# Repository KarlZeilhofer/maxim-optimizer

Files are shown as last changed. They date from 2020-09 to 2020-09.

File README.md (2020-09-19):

# Maxim Optimizer

This KiCad project implements a solar cell optimizer based on the Maxim MAX20801 step down controller with integreated MPPT. 

It's inputs are connected to 3 arrays of 20 to 24 solar cells, they have to be isolated on the input side of the optimizer. 

The outputs of the 3 step down controllers are connected in series. 

This kind of optimizer maximizes the output power for each cell array individually, and works perfectly if some solar modules are shaded partially in a string of many modules. 

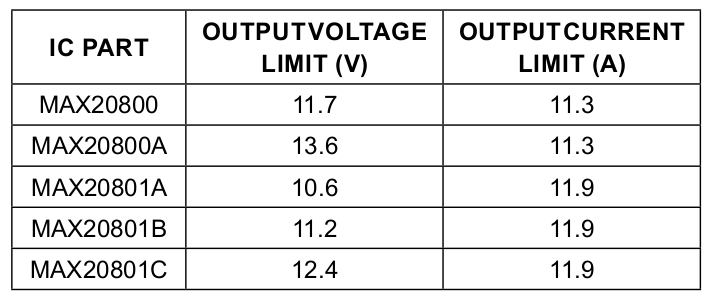
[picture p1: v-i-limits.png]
voltage and current limits


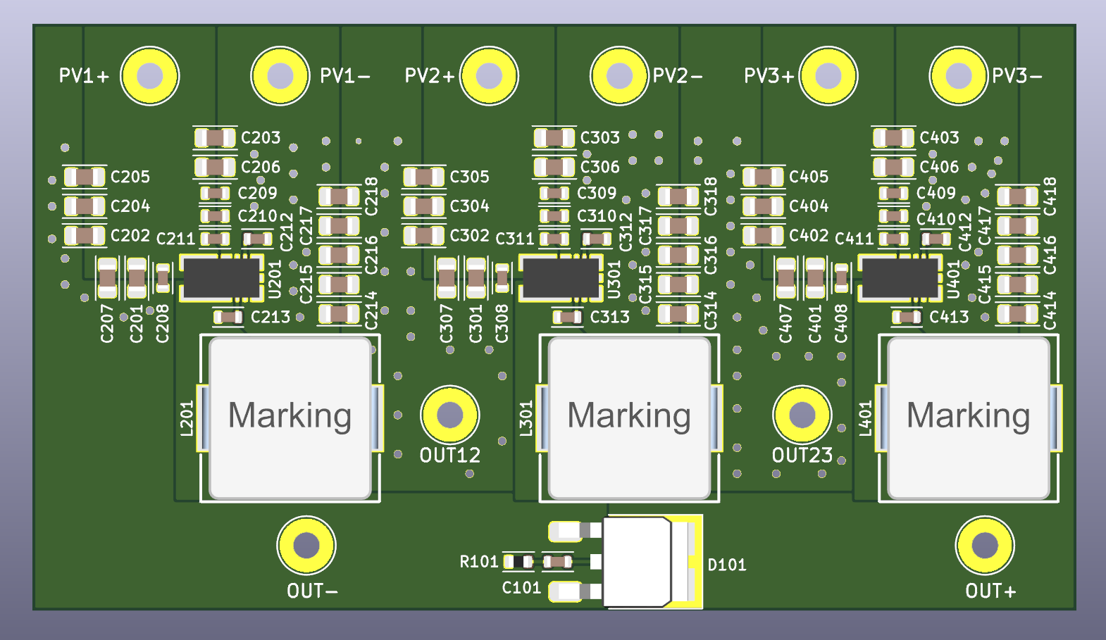
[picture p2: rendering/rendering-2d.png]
2D rendering


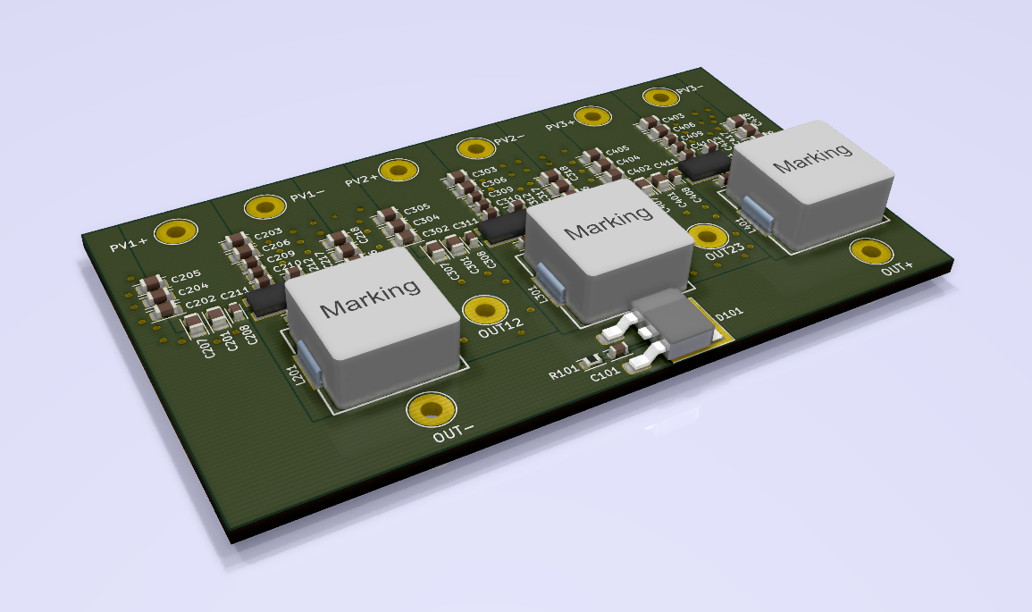
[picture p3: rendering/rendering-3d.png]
3D rendering


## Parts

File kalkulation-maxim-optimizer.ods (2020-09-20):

Kalakulation Maxim-Optimizer, v20.0.0
 |  | preis/stk | preis/bestückung | preis ges
Bezeichnung | Stk | EURct | EURct | EUR | Bemerkung
MAX20801 | 3 | 249 | 1 | 7.50 | Preis von Maxim direkt für 1000 Stk
WE-7443739650068 | 3 | 85 | 2 | 2.61
10u/25v | 36 | 4 | 1 | 1.80 | preis für 16V
PCB, 2x70um, 80x45mm, ENIG | 1 | 53 | 30 | 0.83 | pcbshopper.com
10A/200V MBRB20200CT | 1 | 29 | 2 | 0.31
100n/25v | 12 | 0.16 | 1 | 0.14
1u/6V3 | 3 | 0.95 | 1 | 0.06
220n/6V3 | 3 | 0.3 | 1 | 0.04
10R | 1 | 1 | 1 | 0.02
100n/100V | 1 | 0.7 | 1 | 0.02
Summe |  |  |  | 13.32

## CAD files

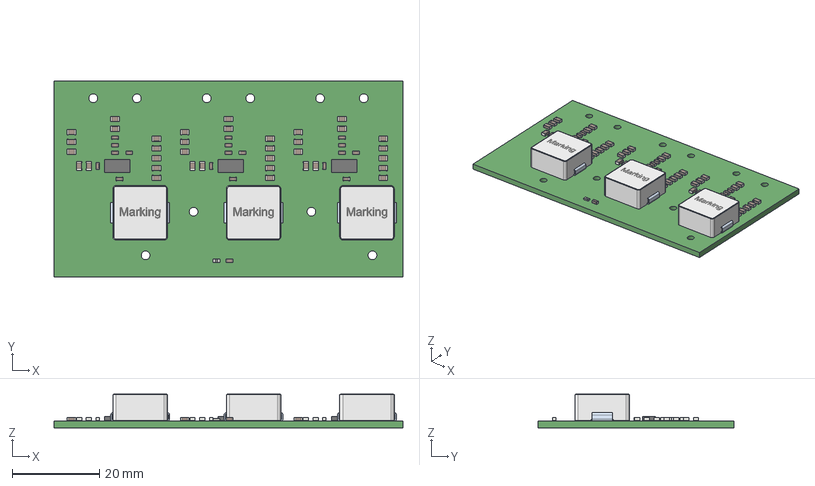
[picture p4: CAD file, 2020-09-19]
rendering/maxim-optimizer.step
80.0 x 45.0 x 7.75 mm
DPAK-2-1EP_GDS

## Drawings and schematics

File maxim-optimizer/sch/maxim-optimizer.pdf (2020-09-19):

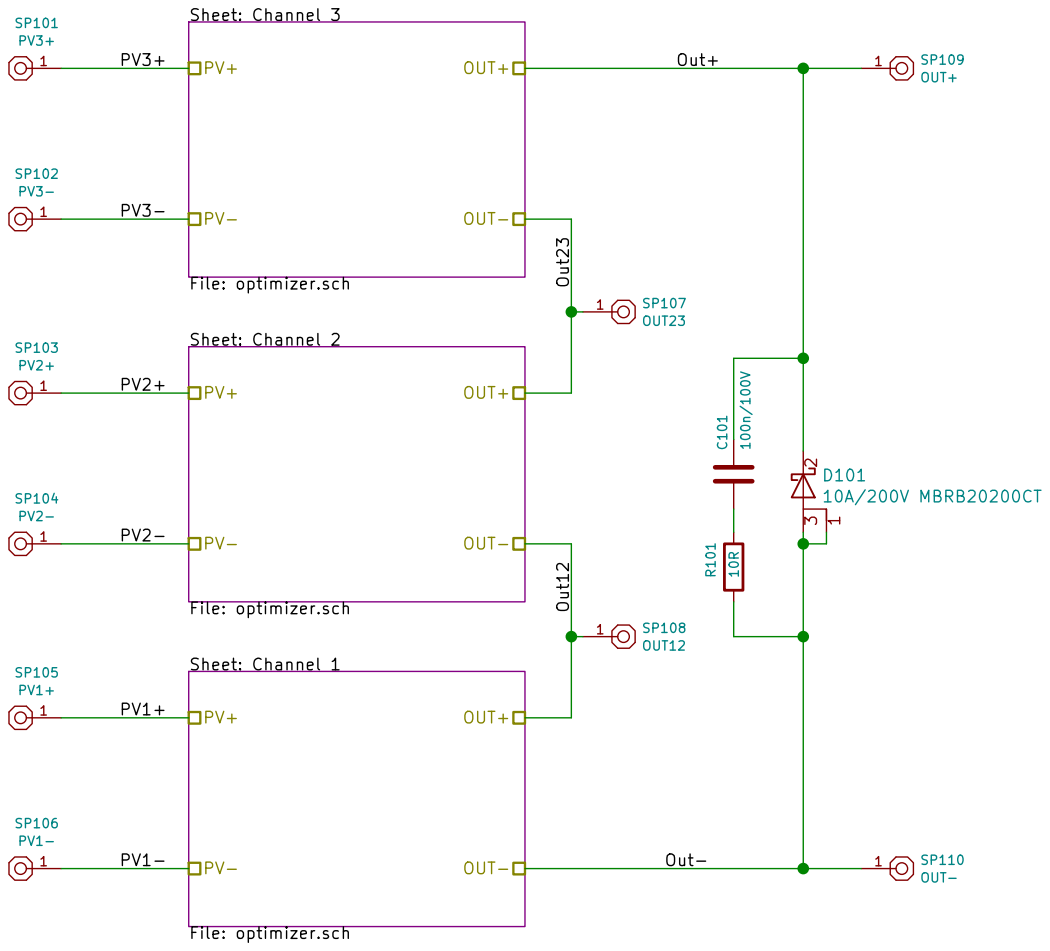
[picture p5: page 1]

File: maxim-optimizer.sch Sheet: / Team14 GesbR

Id: 1/4 Title: Maxim Optimizer

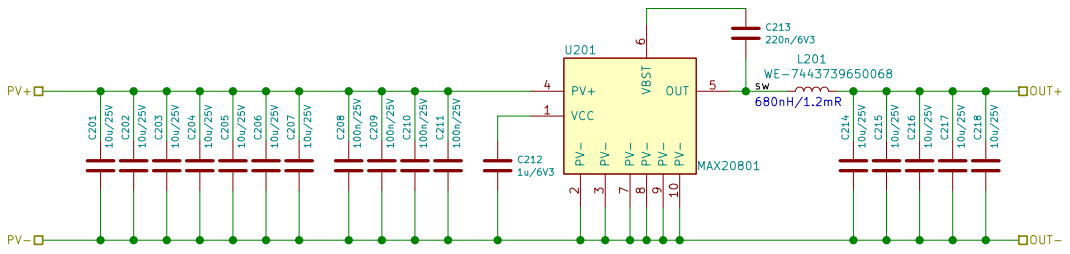
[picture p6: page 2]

6 PV- 7 PV- 8 PV- 9 U201 MAX20801 C201 10u/25V C202 10u/25V C203 10u/25V C204 10u/25V C205 10u/25V C206 10u/25V C207 10u/25V C214 10u/25V C215 10u/25V C216 10u/25V C217 10u/25V C218 10u/25V C209 100n/25V C210 100n/25V L201 WE-7443739650068 C211 100n/25V C213

File: optimizer.sch Sheet: /Channel 1/
Id: 2/4 Title:

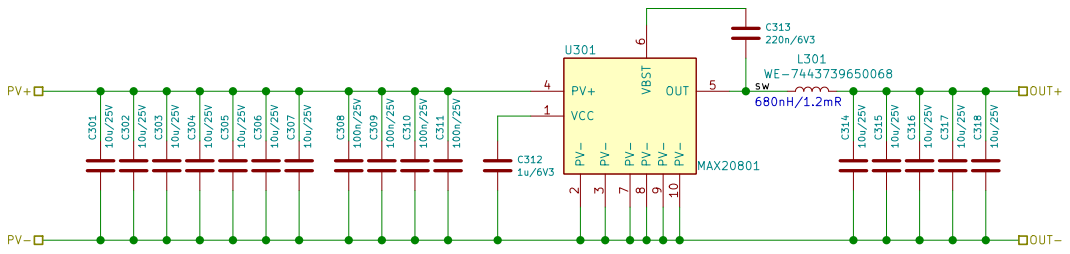
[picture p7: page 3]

6 PV- 7 PV- 8 PV- 9 U301 MAX20801 C301 10u/25V C302 10u/25V C303 10u/25V C304 10u/25V C305 10u/25V C306 10u/25V C307 10u/25V C314 10u/25V C315 10u/25V C316 10u/25V C317 10u/25V C318 10u/25V C309 100n/25V C310 100n/25V L301 WE-7443739650068 C311 100n/25V C313

File: optimizer.sch Sheet: /Channel 2/
Id: 3/4 Title:

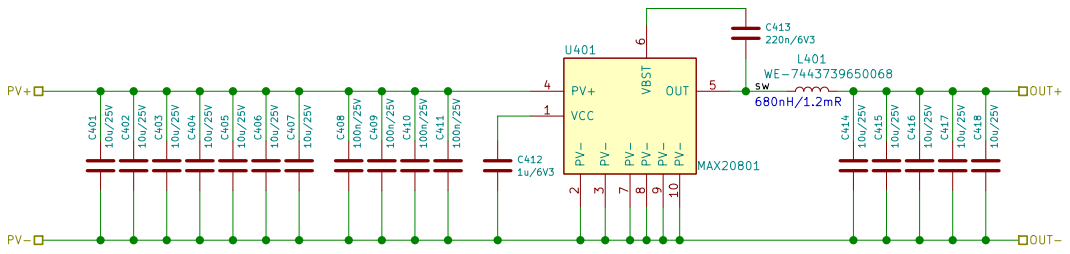
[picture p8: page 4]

6 PV- 7 PV- 8 PV- 9 U401 MAX20801 C401 10u/25V C402 10u/25V C403 10u/25V C404 10u/25V C405 10u/25V C406 10u/25V C407 10u/25V C414 10u/25V C415 10u/25V C416 10u/25V C417 10u/25V C418 10u/25V C409 100n/25V C410 100n/25V L401 WE-7443739650068 C411 100n/25V C413

File: optimizer.sch Sheet: /Channel 3/
Id: 4/4 Title:

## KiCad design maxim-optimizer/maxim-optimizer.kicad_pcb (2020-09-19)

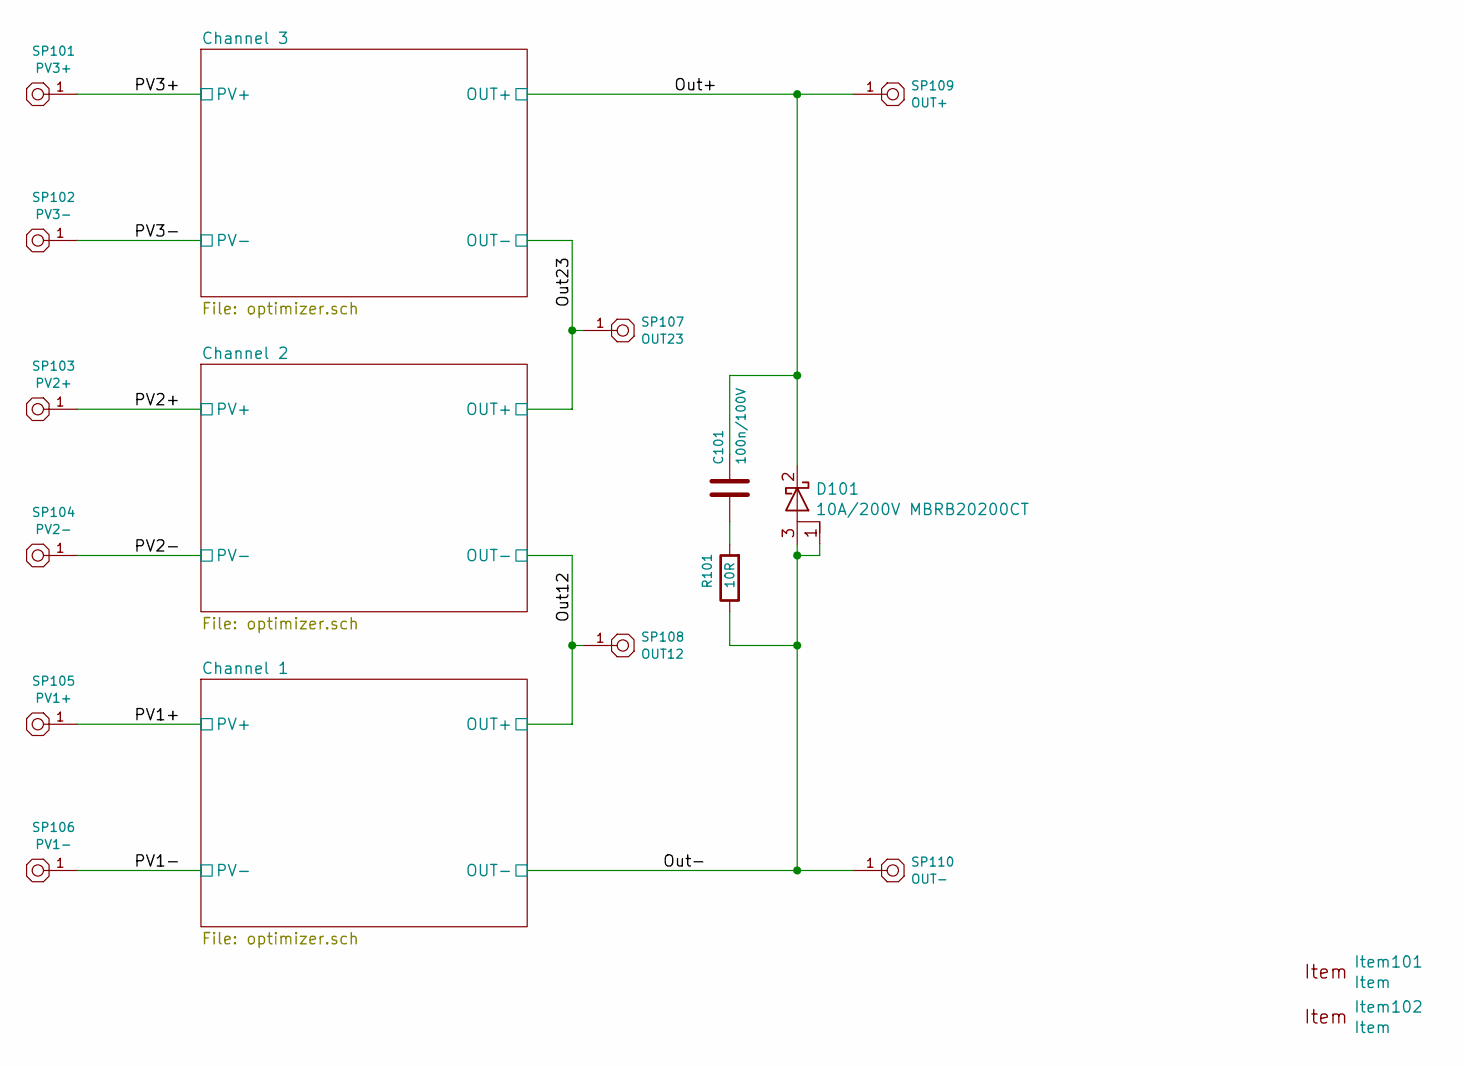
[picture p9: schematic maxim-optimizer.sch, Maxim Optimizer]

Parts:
C101: 100n/100V; C1608m
D101: 10A/200V MBRB20200CT; DPAK-2
Item101: Item; team14-logo-icon-0.47
Item102: Item; team14-logo-schrift-0.47
R101: 10R; R1608m
SP101: PV3+; TestPoint_THTPad_D4.0mm_Drill2.0mm
SP102: PV3-; TestPoint_THTPad_D4.0mm_Drill2.0mm
SP103: PV2+; TestPoint_THTPad_D4.0mm_Drill2.0mm
SP104: PV2-; TestPoint_THTPad_D4.0mm_Drill2.0mm
SP105: PV1+; TestPoint_THTPad_D4.0mm_Drill2.0mm
SP106: PV1-; TestPoint_THTPad_D4.0mm_Drill2.0mm
SP107: OUT23; TestPoint_THTPad_D4.0mm_Drill2.0mm
SP108: OUT12; TestPoint_THTPad_D4.0mm_Drill2.0mm
SP109: OUT+; TestPoint_THTPad_D4.0mm_Drill2.0mm
SP110: OUT-; TestPoint_THTPad_D4.0mm_Drill2.0mm

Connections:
/Out12: SP104.1, SP108.1; also elsewhere on the board
/Out23: SP102.1, SP107.1; also elsewhere on the board
/Out+: C101.1, D101.2 (K), SP109.1; also elsewhere on the board
/Out-: D101.1 (A), D101.3 (A), R101.2, SP106.1, SP110.1; also elsewhere on the board
/PV1+: SP105.1; also elsewhere on the board
/PV2+: SP103.1; also elsewhere on the board
/PV3+: SP101.1; also elsewhere on the board
unnamed: C101.2, R101.1

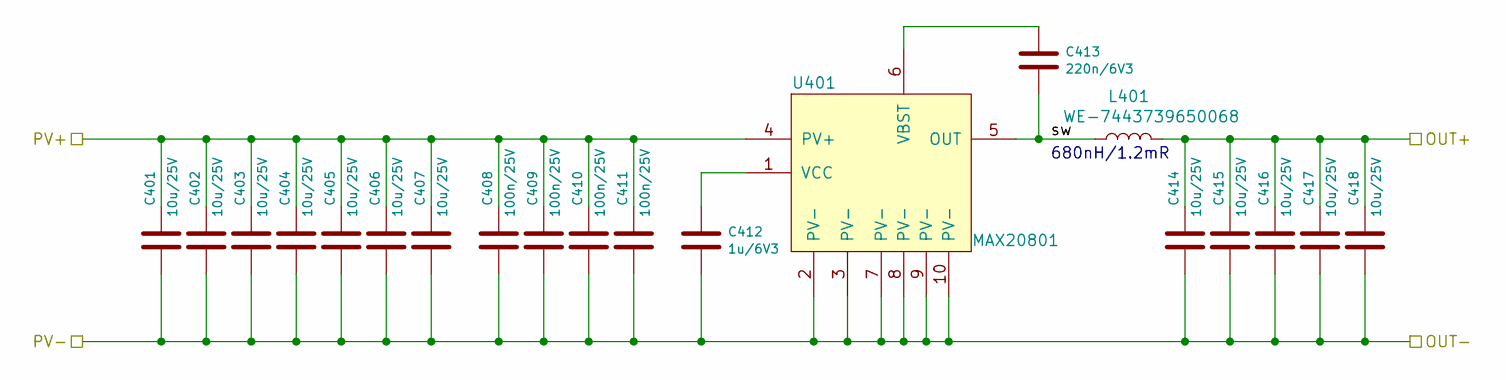
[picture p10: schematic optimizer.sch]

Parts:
C201, C202, C203, C204, C205, C206, C207, C214, C215, C216, C217, C218: 10u/25V; C2012m
C208, C209, C210, C211: 100n/25V; C1608m
C212: 1u/6V3; C1608m
C213: 220n/6V3; C1608m
L201: WE-7443739650068; WE-LHMI_1365
U201: MAX20801

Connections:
/Channel 1/sw: C213.2, L201.1, U201.5 (OUT)
/Out12: C214.1, C215.1, C216.1, C217.1, C218.1, L201.2; also elsewhere on the board
/Out-: C201.2, C202.2, C203.2, C204.2, C205.2, C206.2, C207.2, C208.2, C209.2, C210.2, C211.2, C212.2, C214.2, C215.2, C216.2, C217.2, C218.2, U201.2 (PV-), U201.3 (PV-), U201.7 (PV-), U201.8 (PV-), U201.9 (PV-), U201.10 (PV-); also elsewhere on the board
/PV1+: C201.1, C202.1, C203.1, C204.1, C205.1, C206.1, C207.1, C208.1, C209.1, C210.1, C211.1, U201.4 (PV+); also elsewhere on the board
unnamed: C212.1, U201.1 (VCC)
unnamed: C213.1, U201.6 (VBST)

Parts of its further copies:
C301, C302, C303, C304, C305, C306, C307, C314, C315, C316, C317, C318, C401, C402, C403, C404, C405, C406, C407, C414, C415, C416, C417, C418: 10u/25V; C2012m
C308, C309, C310, C311, C408, C409, C410, C411: 100n/25V; C1608m
C312, C412: 1u/6V3; C1608m
C313, C413: 220n/6V3; C1608m
L301, L401: WE-7443739650068; WE-LHMI_1365
U301, U401: MAX20801

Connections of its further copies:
/Channel 2/sw: C313.2, L301.1, U301.5 (OUT)
/Channel 3/sw: C413.2, L401.1, U401.5 (OUT)
/Out12: C301.2, C302.2, C303.2, C304.2, C305.2, C306.2, C307.2, C308.2, C309.2, C310.2, C311.2, C312.2, C314.2, C315.2, C316.2, C317.2, C318.2, U301.2 (PV-), U301.3 (PV-), U301.7 (PV-), U301.8 (PV-), U301.9 (PV-), U301.10 (PV-); also elsewhere on the board
/Out23: C314.1, C315.1, C316.1, C317.1, C318.1, C401.2, C402.2, C403.2, C404.2, C405.2, C406.2, C407.2, C408.2, C409.2, C410.2, C411.2, C412.2, C414.2, C415.2, C416.2, C417.2, C418.2, L301.2, U401.2 (PV-), U401.3 (PV-), U401.7 (PV-), U401.8 (PV-), U401.9 (PV-), U401.10 (PV-); also elsewhere on the board
/Out+: C414.1, C415.1, C416.1, C417.1, C418.1, L401.2; also elsewhere on the board
/PV2+: C301.1, C302.1, C303.1, C304.1, C305.1, C306.1, C307.1, C308.1, C309.1, C310.1, C311.1, U301.4 (PV+); also elsewhere on the board
/PV3+: C401.1, C402.1, C403.1, C404.1, C405.1, C406.1, C407.1, C408.1, C409.1, C410.1, C411.1, U401.4 (PV+); also elsewhere on the board
unnamed: C312.1, U301.1 (VCC)
unnamed: C313.1, U301.6 (VBST)
unnamed: C412.1, U401.1 (VCC)
unnamed: C413.1, U401.6 (VBST)

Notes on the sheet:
680nH/1.2mR

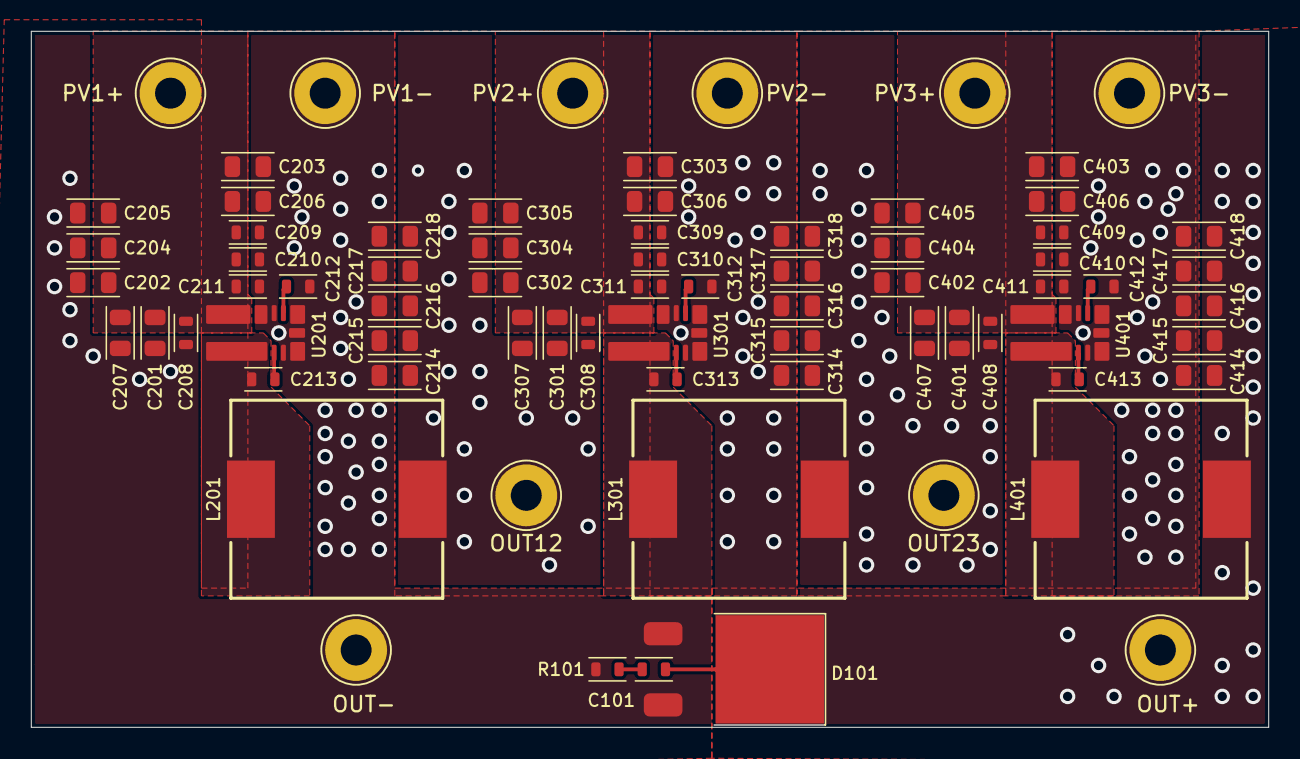
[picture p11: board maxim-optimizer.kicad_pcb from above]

Board: 2 copper layers, 80.0 x 45.0 mm, 75 parts (0 on the bottom side), 17 nets.

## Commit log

2020-09-19 v20.0.0 preliminary
    [kalkulation-maxim-optimizer.ods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]
2020-09-19 as ordered
    [kalkulation-maxim-optimizer.ods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]
2020-09-20 updated cost calculation
    [kalkulation-maxim-optimizer.ods]
